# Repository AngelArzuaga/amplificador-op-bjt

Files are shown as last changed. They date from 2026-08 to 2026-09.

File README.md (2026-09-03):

# Amplificador Operacional con BJTs

Diseño de un amplificador operacional discreto construido con transistores BJT, incluyendo esquemático, simulación en LTspice y layout en KiCad.
### Integrantes:
Ángel Arzuaga, María Camila Castilla, Cristian Sepúlveda y Esteban Toro

## Descripción

Este proyecto consiste en construir, desde cero, un amplificador operacional usando transistores bipolares individuales, en lugar de partir de un circuito integrado ya armado. La idea es entender cómo funciona por dentro un componente que normalmente se usa como una "caja negra", diseñando cada etapa del circuito; entrada, amplificación y salida.

Una vez terminado el diseño, se puso a prueba el circuito en dos configuraciones clásicas para verificar que funcionara correctamente. La primera fue como amplificador no inversor con ganancia 2, es decir, la señal de salida sale duplicada respecto a la de entrada, manteniendo la misma polaridad. La segunda fue como buffer (o seguidor de voltaje), una configuración que no amplifica la señal pero es muy útil para aislar etapas de un circuito sin alterar el voltaje que pasa por ellas.

## Simulación en LTspice

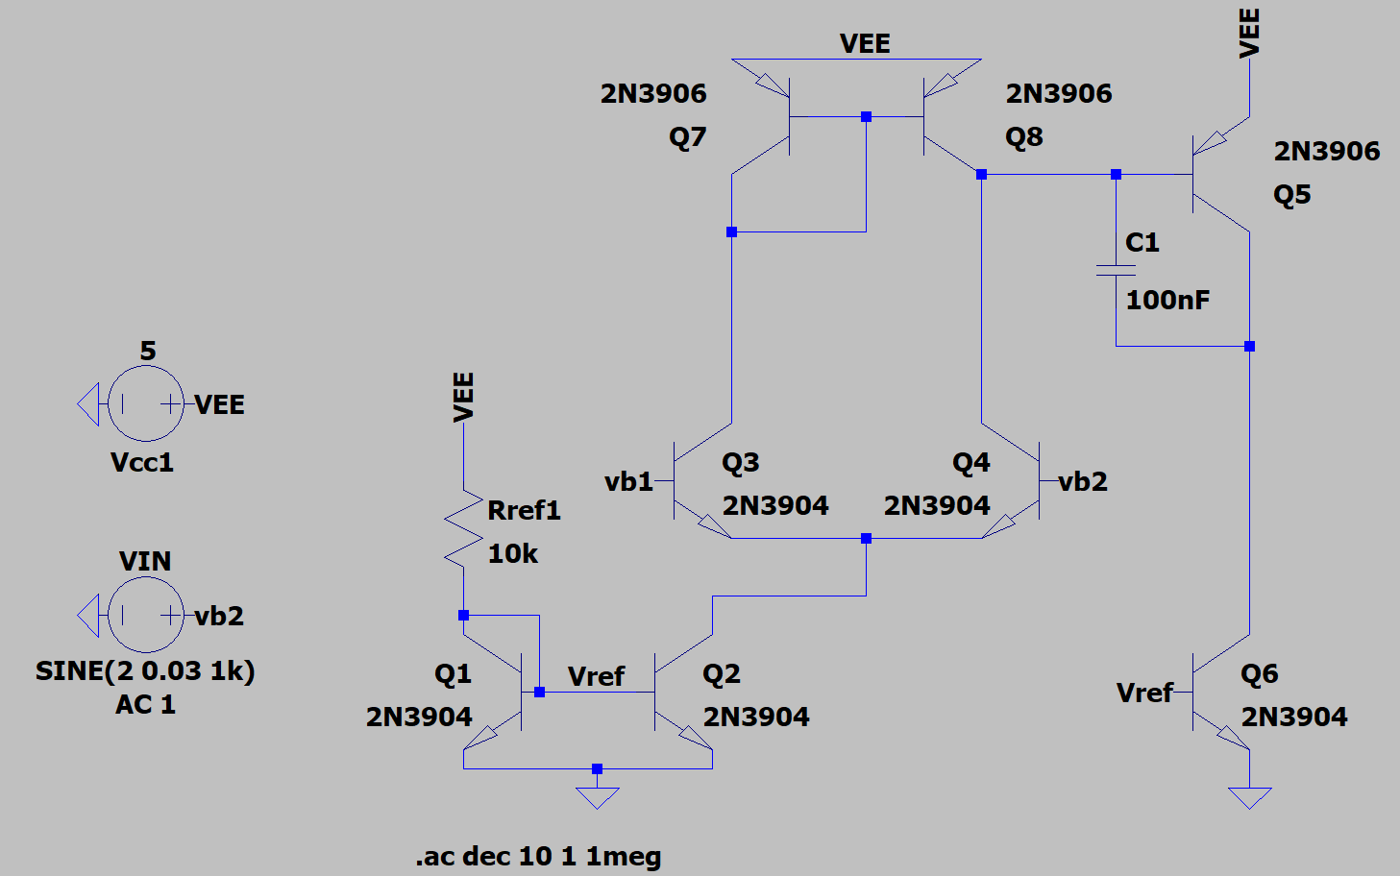
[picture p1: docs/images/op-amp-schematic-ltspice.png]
Resultados de simulación

*Esquemático simulado en LTspice, base de los resultados de ganancia y ancho de banda.*

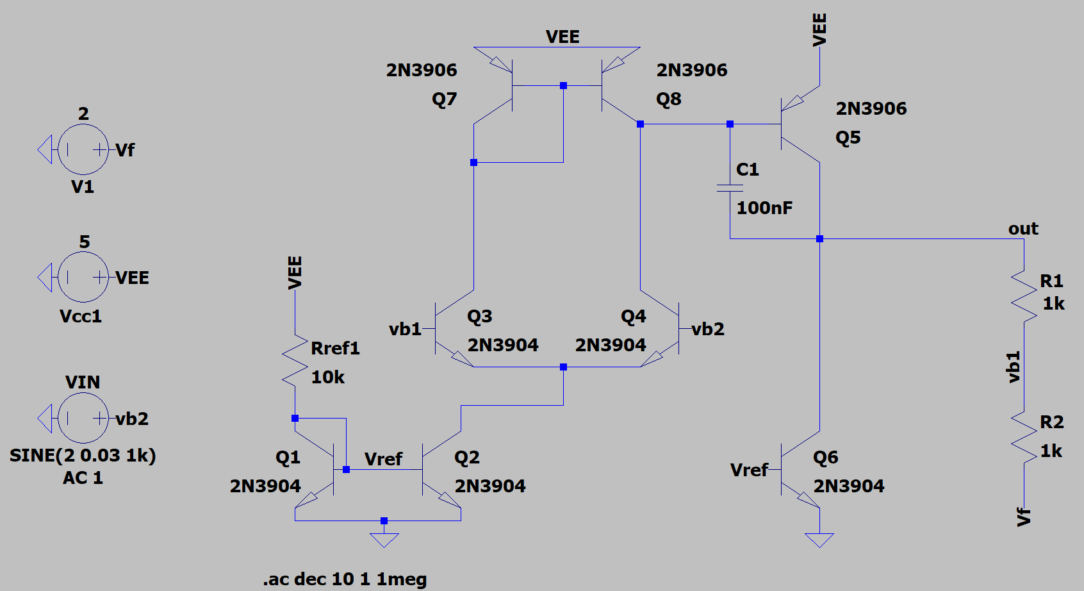
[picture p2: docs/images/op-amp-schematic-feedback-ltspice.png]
Resultados de simulación con feedback

*Esquemático simulado en LTspice, en configuración no inversora de ganancia 2.*

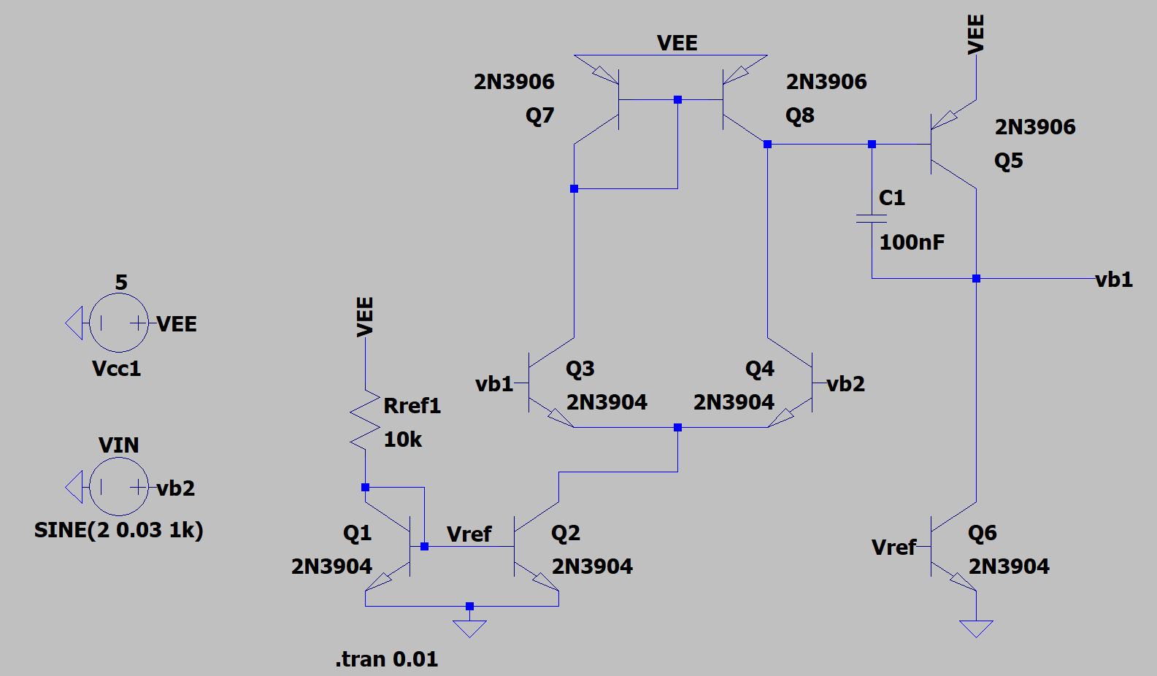
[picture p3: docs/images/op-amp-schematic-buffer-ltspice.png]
Resultados de simulación como buffer

*Esquemático simulado en LTspice, en configuración de buffer.*

## Esquemático en KiCad

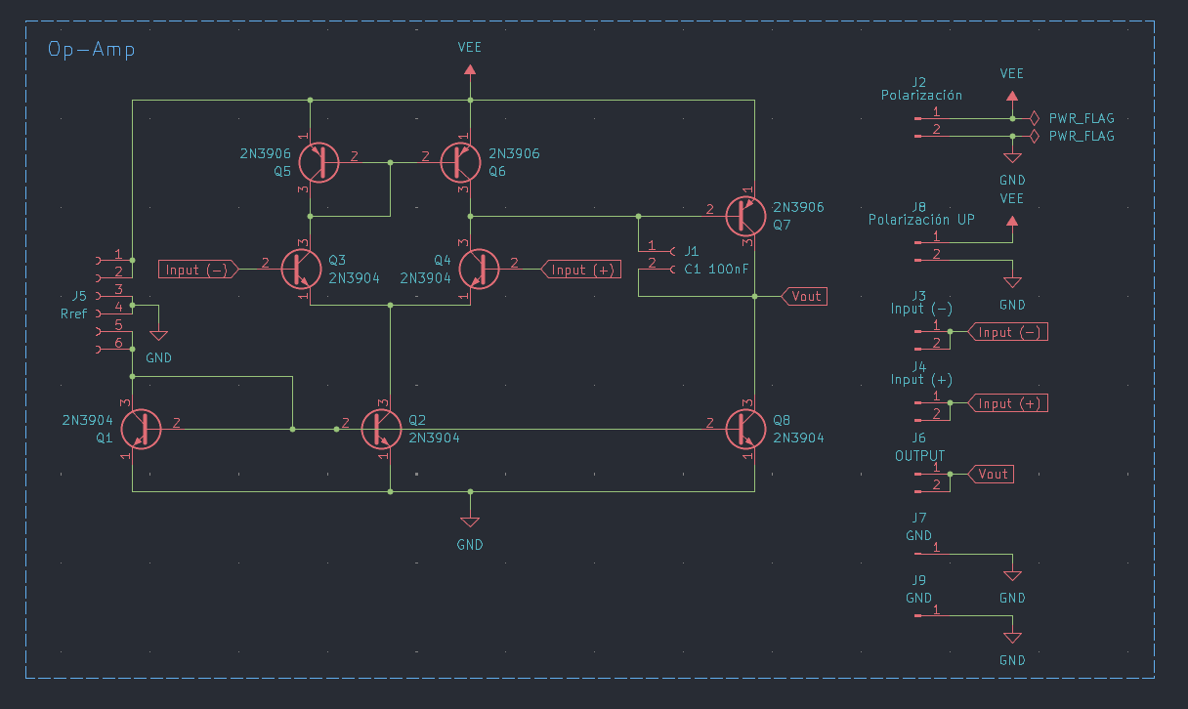
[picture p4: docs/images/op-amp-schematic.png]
Esquemático

*Esquemático completo del amplificador diseñado en KiCad.*

## PCB

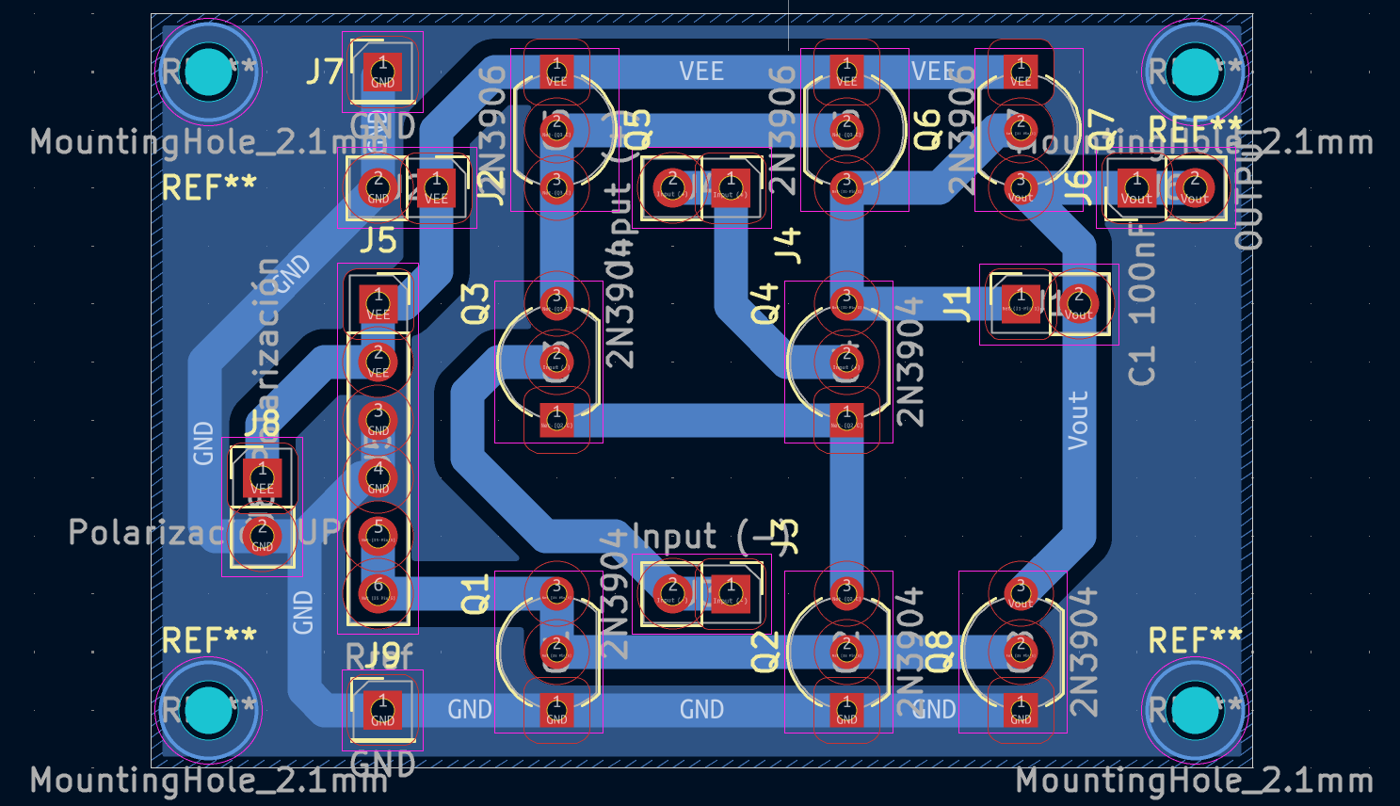
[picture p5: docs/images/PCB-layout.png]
Layout del PCB

*Distribución de componentes y pistas del PCB.*

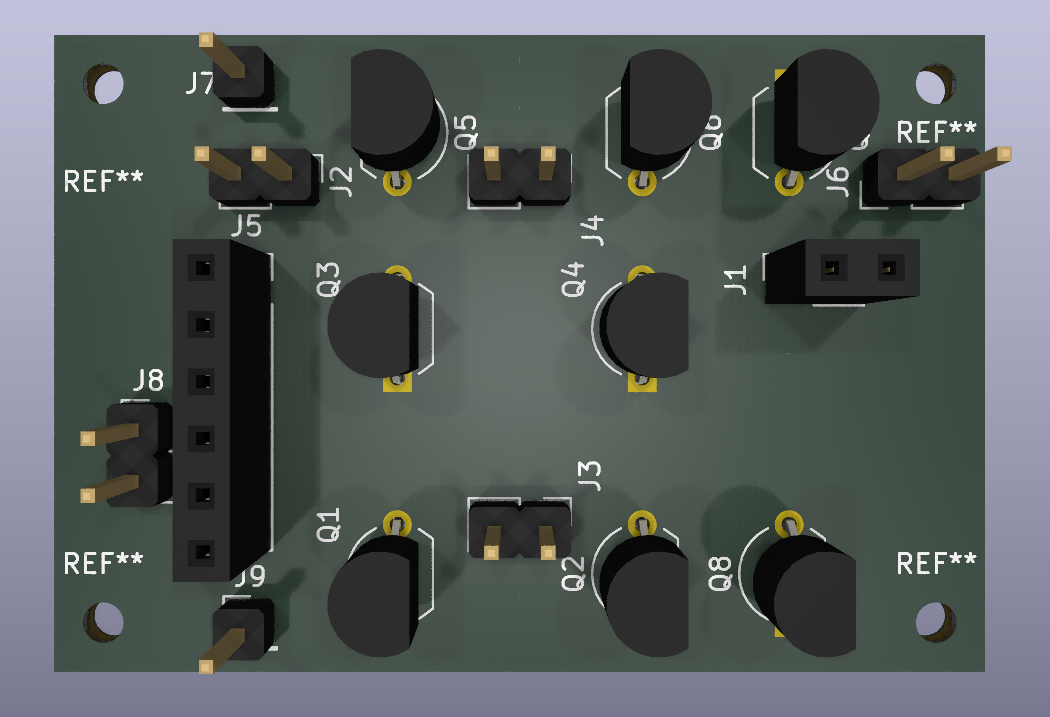
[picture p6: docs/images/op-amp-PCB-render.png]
Render del PCB

*Render 3D del PCB terminado.*

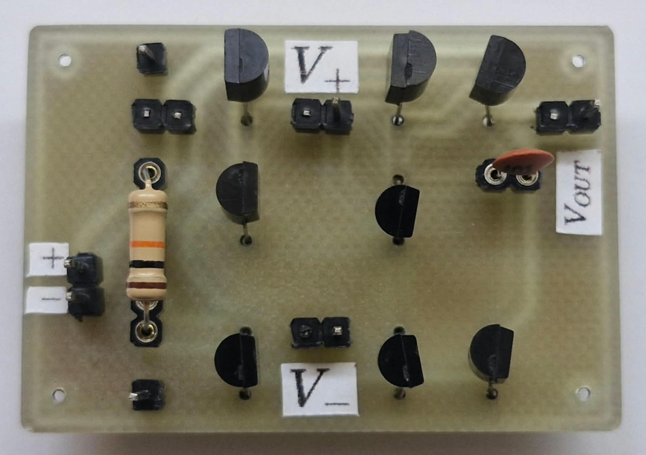
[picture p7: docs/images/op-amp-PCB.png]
PCB


*PCB terminado con componentes soldados.*

## Componentes utilizados

| Componente | Valor / Modelo | Datasheet |
|---|---|---|
| NPN | 2N3904 | [datasheet](datasheets/2N3904.pdf) |
| PNP | 2N3906 | [datasheet](datasheets/2N3906.pdf) |
| $R_{ref}$ | 10 kΩ | — |
| $C_1$ | 100 nF | — |

El amplificador se diseño para que tanto $R_{ref}$ como $C_1$ puedan ser intercambiables a gusto del diseñador o usuario final.

## Estructura del repositorio

```
amplificador-op-bjt/
├── kicad/          # Esquemático y PCB (KiCad)
├── ltspice/         # Simulaciones y resultados (LTspice)
├── datasheets/       # Hojas de datos de los componentes usados
├── docs/
│   └── images/         # Capturas de esquemático, gráficas, fotos
├── gerbers/           # Archivos de fabricación del PCB
└── LICENSE
```

## Cómo abrir los archivos

**KiCad** (versión 9.0 o superior):
1. Abre KiCad
2. File → Open Project → selecciona `kicad/amp-op-bjt.kicad_pro`

**LTspice**:
1. Abre LTspice
2. File → Open → selecciona el archivo `.asc` dentro de `ltspice/`
3. Ejecuta la simulación con Simulate → Run

## Licencia

Este proyecto está licenciado bajo **CERN-OHL-P v2**. Ver [LICENSE](LICENSE) para el texto completo.

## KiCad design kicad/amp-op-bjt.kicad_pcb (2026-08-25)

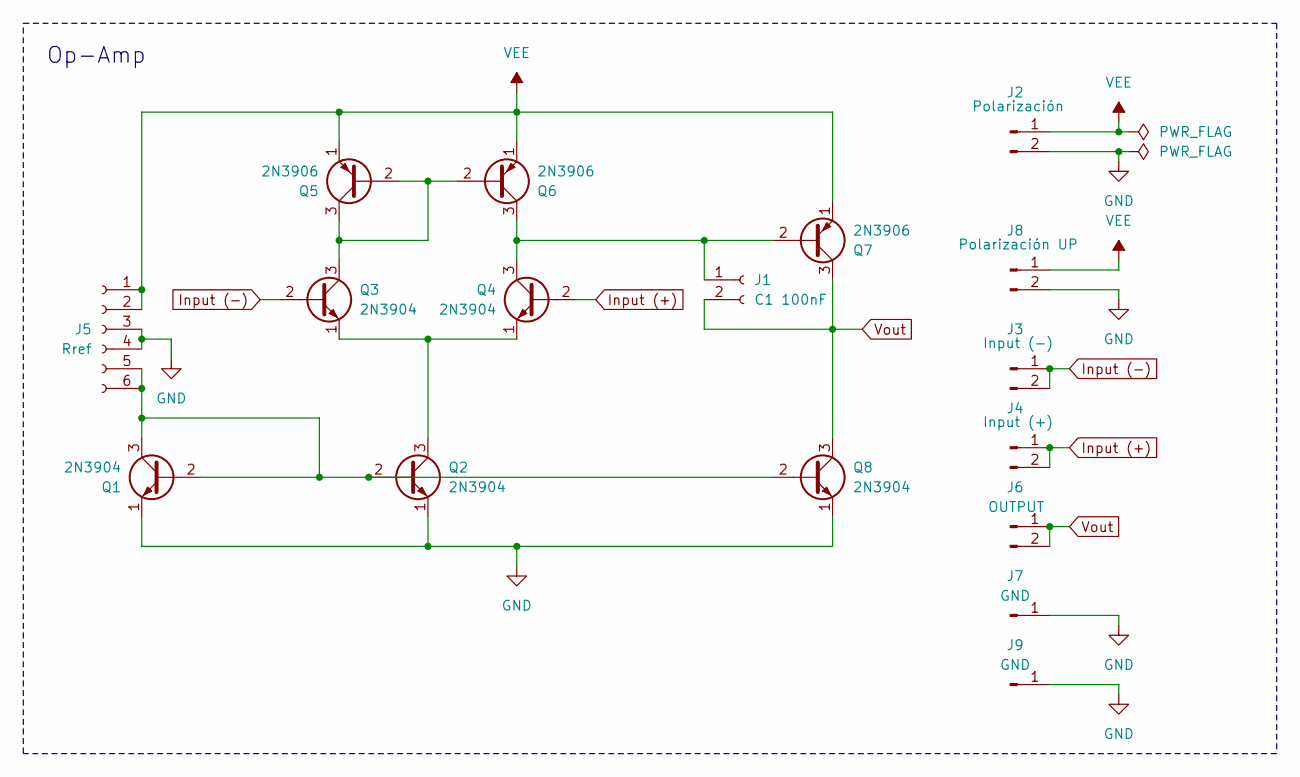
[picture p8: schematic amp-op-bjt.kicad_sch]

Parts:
J1: C1 100nF; PinSocket_1x02_P2.54mm_Vertical
J2: Polarización; PinHeader_1x02_P2.54mm_Vertical
J3: Input (-); PinHeader_1x02_P2.54mm_Vertical
J4: Input (+); PinHeader_1x02_P2.54mm_Vertical
J5: Rref; PinSocket_1x06_P2.54mm_Vertical
J6: OUTPUT; PinHeader_1x02_P2.54mm_Vertical
J7, J9: GND; PinHeader_1x01_P2.54mm_Vertical
J8: Polarización UP; PinHeader_1x02_P2.54mm_Vertical
Q1, Q2, Q3, Q4, Q8: 2N3904; TO-92_Inline_Wide
Q5, Q6, Q7: 2N3906; TO-92_Inline_Wide

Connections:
GND: J2.2, J5.3, J5.4, J7.1, J8.2, J9.1, Q1.1 (E), Q2.1 (E), Q8.1 (E)
Input (+): J4.1, J4.2, Q4.2 (B)
Input (-): J3.1, J3.2, Q3.2 (B)
unnamed: J1.1, Q4.3 (C), Q6.3 (C), Q7.2 (B)
unnamed: J5.5, J5.6, Q1.2 (B), Q1.3 (C), Q2.2 (B), Q8.2 (B)
unnamed: Q2.3 (C), Q3.1 (E), Q4.1 (E)
unnamed: Q3.3 (C), Q5.2 (B), Q5.3 (C), Q6.2 (B)
VEE: J2.1, J5.1, J5.2, J8.1, Q5.1 (E), Q6.1 (E), Q7.1 (E)
Vout: J1.2, J6.1, J6.2, Q7.3 (C), Q8.3 (C)

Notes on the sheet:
Op-Amp

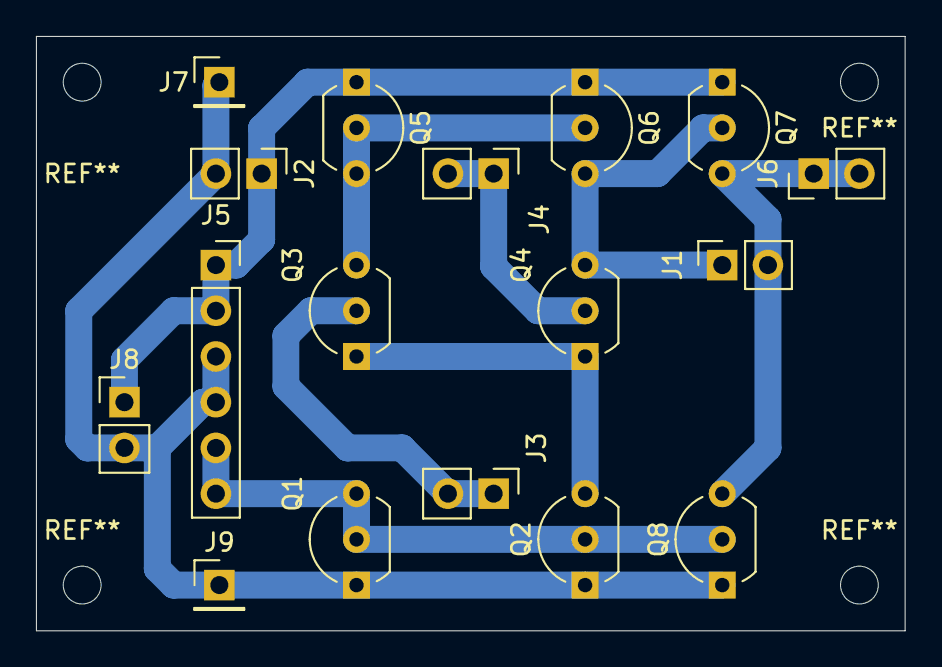
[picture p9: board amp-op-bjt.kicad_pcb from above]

Board: 2 copper layers, 48.3 x 33.0 mm, 17 parts (0 on the bottom side), 9 nets.

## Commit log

2026-08-25 Estructura inicial del proyecto: KiCad, LTspice, README y licencia
    [amp-op-bjt-B_Cu.gbr, amp-op-bjt-B_Mask.gbr, amp-op-bjt-B_Paste.gbr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]
2026-08-29 acturaliza imágenes de simulación
2026-08-29 agrega imágen del PCB
